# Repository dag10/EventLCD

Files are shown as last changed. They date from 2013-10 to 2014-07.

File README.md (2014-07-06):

EventLCD
========

A project using an Arduino Ethernet and LCD character display to show upcoming events in a location from a shared Google calendar.

Pictures and more info can be found on [my blog](http://drewgottlieb.net/2014/03/02/opensource-event-display.html).

Details
-------

### Hardware

The hardware consists of:
 - Arduino Ethernet w/ a POE (Power Over Ethernet) module [Amazon Link](http://www.amazon.com/gp/product/B005D22FR6/ref=oh_details_o03_s00_i00)
 - 20x4 Amerlight LCD Module with HD44780 controller [Amazon Link](http://www.amazon.com/gp/product/B00D7Z2BWU/ref=oh_details_o09_s00_i01)
 - Custom PCB for connecting the Arduino with the LCD module (see /pcb)
   - 74LS595 Shift register
   - 10K Trim potentiometer
   - 16-pin header row
 - Generic project enclosure
 - POE Injector

### Software

 - Flask-powered web server that pulls the events from Google Calendar and renders a 20x4 character HTTP response containing what the LCD should display. (see /website)
   - Configurable items: Google API token, Google Calendar ID
 - C++ Arduino code. (see /arduino)
   - Configurable items: MAC address

Hardware Instructions
--------

1. Drill out your enclosure to expose the LCD screen and Arduino's ethernet port.
2. Solder shift register and trimpot onto custom PCB.
3. Solder wires to pads on custom PCB.
4. Solder custom PCB onto back of LCD module with header pins.
5. Attach (perhaps with hot glue) the LCD module and Arduino into the enclosure.
6. Plug those wires onto the Arduino's pins. Look at the Arduino code for pin mapping.
7. Install the software (see below), and you're done! Just plug it into powered ethernet.

Software Instructions
--------

### Arduino sketch

I'm using [ino](http://inotool.org) to build the arduino code. If you use ino, you must delete the Robot_Control library from your Arduino IDE installation ([explanation here](https://github.com/amperka/ino/issues/85)).

To use ino, navigate to the arduino directory and run `ino build` then `ino upload`. If you build using the Arduino IDE, make sure to add the libraries in the lib folder.

### Web application

Go to the website directory and run setup.sh to install the virtualenv with flask and its extensions. Then copy app.yaml.example to app.yaml and insert your Google API token and Google calendar ID.

To run the app, execute `./run.py`.

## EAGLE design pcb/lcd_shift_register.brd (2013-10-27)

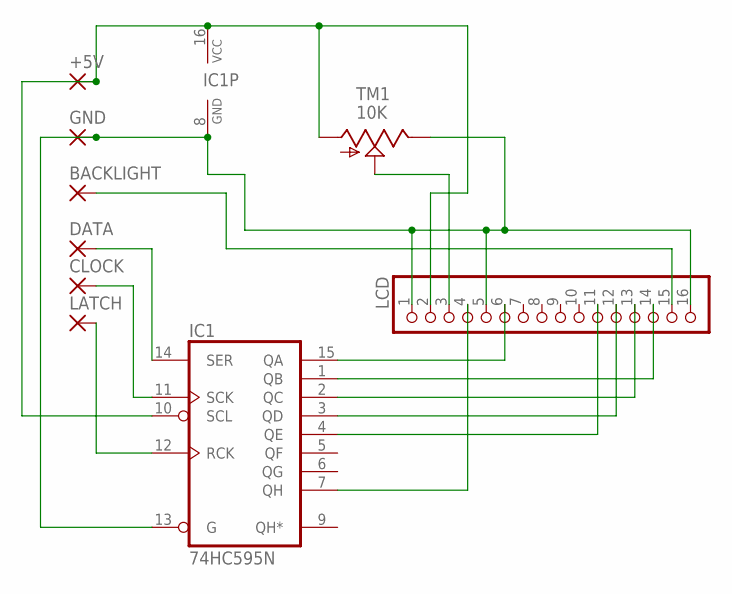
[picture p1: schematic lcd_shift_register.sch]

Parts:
+5V: 2,15/1,0
BACKLIGHT: 2,15/1,0
CLOCK: 2,15/1,0
DATA: 2,15/1,0
GND: 2,15/1,0
IC1: 74HC595N; DIL16
LATCH: 2,15/1,0
LCD: PINHD-1X16; 1X16
TM1: 10K; 6MM

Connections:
unnamed: +5V.1, IC1.10 (SCL), IC1.16 (VCC), LCD.2, TM1.A
unnamed: GND.1, IC1.8 (GND), IC1.13 (G), LCD.1, LCD.5, LCD.16, TM1.E
unnamed: BACKLIGHT.1, LCD.15
unnamed: LCD.3, TM1.S
unnamed: DATA.1, IC1.14 (SER)
unnamed: IC1.12 (RCK), LATCH.1
unnamed: CLOCK.1, IC1.11 (SCK)
unnamed: IC1.1 (QB), LCD.14
unnamed: IC1.2 (QC), LCD.13
unnamed: IC1.3 (QD), LCD.12
unnamed: IC1.4 (QE), LCD.11
unnamed: IC1.15 (QA), LCD.6
unnamed: IC1.7 (QH), LCD.4

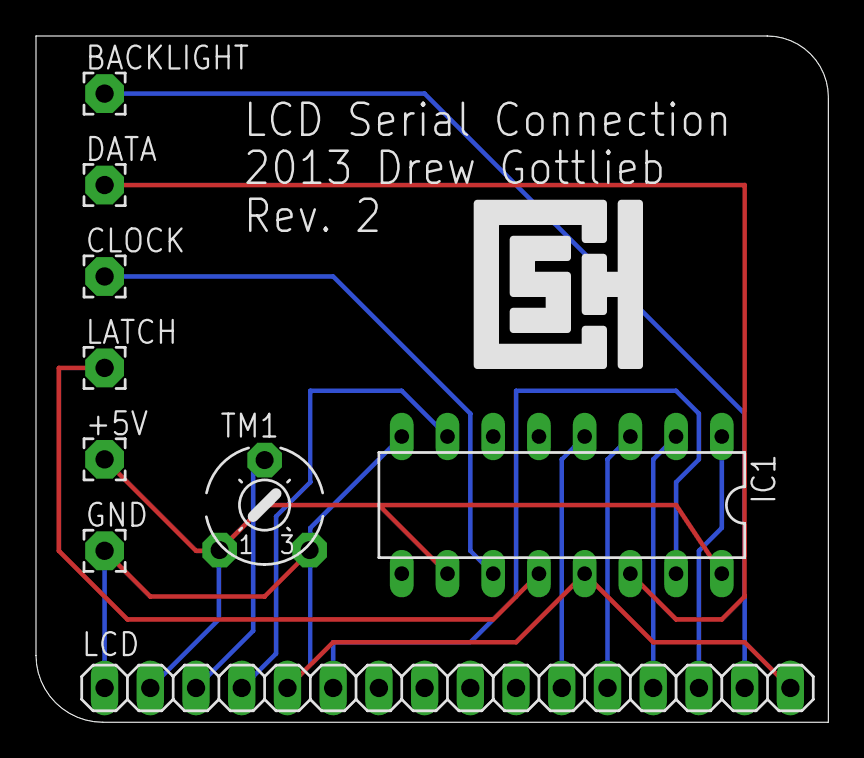
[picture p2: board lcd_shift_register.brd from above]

Board: 2 copper layers, 44.0 x 38.1 mm, 9 parts (0 on the bottom side), 13 nets.

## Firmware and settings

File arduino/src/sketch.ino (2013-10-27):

/* Event LCD Arduino code.
 * Copyright 2013 Drew Gottlieb
 */

#include "backlight.h"
#include "display.h"
#include "request.h"
#include <inttypes.h>

// Pins
uint8_t pin_backlight = 9;
uint8_t pin_lcd_data = 7;
uint8_t pin_lcd_clock = 6;
uint8_t pin_lcd_latch = 5;

// Settings
const int delay_interval = 10; // milliseconds between ticks in sleep()
uint8_t mac[] = {0x90, 0xA2, 0xDA, 0x0D, 0xBE, 0x94}; // MAC of board
const float refresh_interval = 20; // seconds between each refresh TODO make 20
const float reconnect_interval = 10; // seconds between reconnection attempts
const int max_http_retries = 3; // max HTTP retry attempts before iface retry
const char *domain = "rancor.csh.rit.edu"; // domain of website
const uint16_t port = 5000; // port of website
const char *location = "lounge"; // location to search for in calendar
const char *location_full = "Lounge"; // location to display on screen
const uint8_t lcd_width = 20; // characters in each LCD row
const uint8_t lcd_height = 4; // rows in LCD display

// Controllers
Backlight backlight(pin_backlight);
Display display(
    pin_lcd_data, pin_lcd_clock, pin_lcd_latch, lcd_width, lcd_height);
Request request;

// Functions
void setup();
void loop();
bool maintainLease();
void updateDisplay();
void sleep(float seconds);

// Variables
bool connected = false;
uint8_t retries = 0;
char *url;

// Init
void setup() {
  // Initialize display
  backlight.setBrightness(100);
  display.setScreen(SCREEN_NETWORK);
  display.setMAC(mac);
  display.setNetworkStatus(CONNECTING);

  // Wait for brightness to fade up
  while (backlight.getRealBrightness() < backlight.getBrightness())
    sleep(0.1);

  // Create URL path
  const char *url_format = "/location/%s/events";
  url = new char[strlen(url_format) - 2 + strlen(location) + 1];
  sprintf(url, url_format, location);
}

// Loop
void loop() {
  // Make sure we're still connected to the network
  while (!connected) {
    connected = Ethernet.begin(mac);
    if (!connected) {
      display.setScreen(SCREEN_NETWORK);
      display.setNetworkStatus(DHCP_FAILED);
      backlight.flash(2);
      sleep(30);
      display.setNetworkStatus(CONNECTING);
      sleep(0.1);
    }
  }

  // We're connected now, so update display
  display.setNetworkStatus(CONNECTED);
  display.setIP(Ethernet.localIP());
  sleep(1);

  // Maintain DHCP lease to make sure we're still totally connected
  do {
    request.setup(domain, url, port);
    display.setRequest(&request);

    // Step through the HTTP request
    while (request.step())
      if (display.getScreen() == SCREEN_NETWORK)
        updateDisplay();
    
    // HTTP request failed, so display error message and wait a moment
    if (request.failed()) {
      display.setScreen(SCREEN_NETWORK);
      backlight.flash(2);
      sleep(reconnect_interval);

      // If it tries reconnecting to HTTP too many times, try reconnecting
      // on the interface itself.
      if (++retries >= max_http_retries)
        break;

      continue;
    }
    retries = 0;
    char *response = (char*)request.getData();

    // Parse requested backlight brightness from response body
    for (char *c = response; *c; c++) {
      if (*c == '\n') {
        *c = 0;
        backlight.setBrightness(atoi(response) / 255.f * 100.f);
        response = c + 1;
        break;
      }
    }

    // Show HTTP response body on screen then wait a bit before refreshing
    display.setScreen(SCREEN_TEXT);
    display.setContent(response);
    sleep(refresh_interval);
  } while (maintainLease());

  // Disconnected (failed to maintain), so wait a bit before reconnecting
  display.setScreen(SCREEN_NETWORK);
  display.setNetworkStatus(DISCONNECTED);
  backlight.flash(2);
  sleep(reconnect_interval);
  display.setNetworkStatus(RECONNECTING);
  sleep(0.1);
  connected = false;
}

// Maintains the DHCP lease, returns true if connection still good
bool maintainLease() {
  uint8_t maintain_status = Ethernet.maintain();
  return maintain_status == 0 || maintain_status % 2 == 0;
}

// Update display
void updateDisplay() {
  static unsigned long last_update = millis() - 1;
  float elapsed = (millis() - last_update) / 1000.f;
  display.update(elapsed);
  backlight.update(elapsed);
  last_update = millis();
}

// Pause the program, but continue updating the display
void sleep(float seconds) {
  unsigned long target = millis() + (seconds * 1000);
  while (millis() < target) {
    updateDisplay();
    delay(delay_interval);
  }
}

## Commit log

2013-10-16 Created display controller with basic network status screen. Connects to ethernet, but doesn't manage to display if connected or not.
    [sketch.ino]
2013-10-16 Added simple build notes for arduino sketch.
2013-10-21 Arduino fetches plain-text web page and displays it once.
2013-10-21 Restructured sketch program flow to handle issues well.
    Backlight flashes on errors.
    Moved move things to settings, such as room name and url.
    [sketch.ino]
2013-10-22 Client disconnects on error.
    Refresh rate changed to 20 seconds.
    [sketch.ino]
2013-10-22 Current events shown with a 'NOW: ' in front.
2013-10-22 Filter out all-day events.
2013-10-23 Fixed Arduino.h includes.
2013-10-23 Fixed url char allocation to maybe fix crash problem. Also only updates screen during request if screen is network.
    Also added subtle pulsing to backlight as a heartbeat.
    [sketch.ino]
2013-10-27 Added PCB schematics of rev2.
    This is the version sent off to OSHPark for the first batch.
    [DRILEGEND.CFG, lcd_shift_register.brd, lcd_shift_register.sch]
